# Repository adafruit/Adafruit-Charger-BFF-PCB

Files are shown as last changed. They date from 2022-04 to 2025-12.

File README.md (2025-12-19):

## Adafruit Charger BFF for QT Py PCB

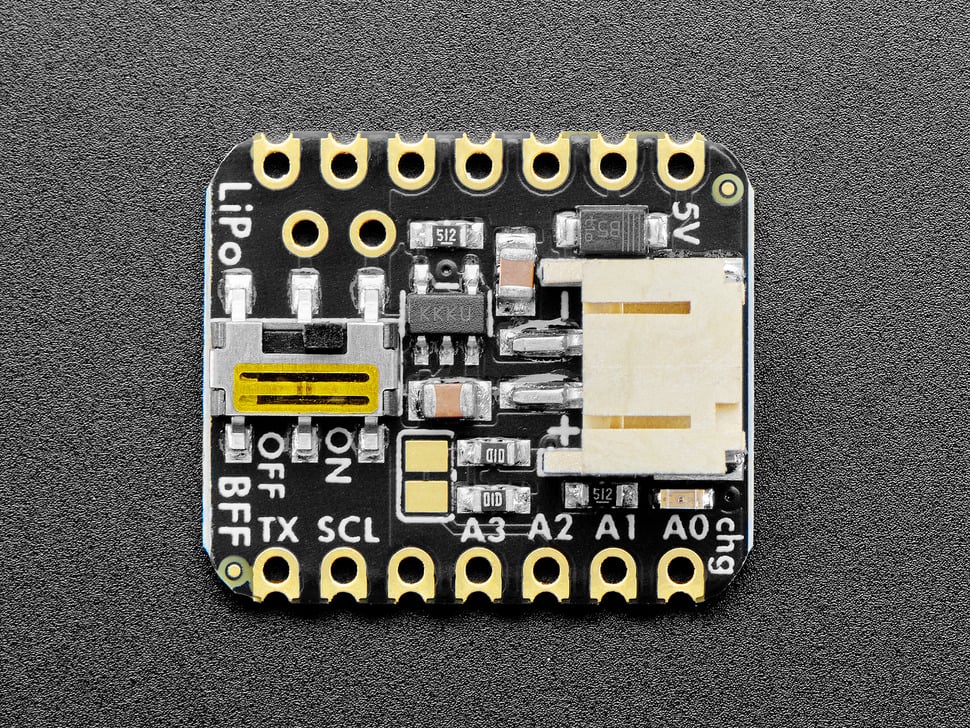
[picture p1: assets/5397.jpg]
<a href="http://www.adafruit.com/products/5397"><br/>
Click here to purchase one from the Adafruit shop</a>

PCB files for the Adafruit Charger BFF for QT Py. 

Format is EagleCAD schematic and board layout
* https://www.adafruit.com/product/5397

### Description

Is your QT Py all alone, lacking a friend to travel the wide world with? When you were a kid you may have learned about the "buddy" system, well this product is kinda like that! A board that will watch your QT Py's back and give it the power and support to wander out past your USB port.

This little lipo charger is designed to fit onto the back of any QT Py board, and make it easy for portable powering. Simply plug any standard 3.7V/4.2V lithium polymer or lithium-ion rechargeable battery into the JST plug on the end. When powered by the USB port on the QT Py, the charger kicks in and will charge up the battery at 200mA max rate. You'll see the yellow LED light up when that happens.

When the USB is removed, the battery will reverse charge into the 5V port via a Schottky diode. You can turn it on or off with the built in slide switch as well.

A simple voltage divider on the cathode side of the diode and connected to pin A2 will let your firmware detect basic modes: if the voltage is over 4.3V, it is probably plugged into USB. If the voltage is 4.2V or below its probably running on the Lipoly battery and you can roughly determine the battery state.

We include some header that you can solder to your QT Py. You can also pick up an Itsy Bitsy short female header kit to make it removable but compact, you'll just need to trim down the headers to 7 pins long.

For use with Adafruit LiPoly/LiIon batteries only! Other batteries may have different voltage, chemistry, polarity, or pinout.

* Comes as an assembled and tested PCB
* Uses the 5V input via USB Type-C connector on QT Py
* For charging single Lithium Ion/Lithium Polymer 3.7/4.2v batteries (not for older 3.6/4.1v cells)
* 200mA charge current

Batteries and QT Py are not included.

<b>Revision History:

* As of December 12, 2025 - </b> We added two breakout pads for the on/off switch for an external switch if desired. We also updated the PCB with Adafruit Pinguin to make a lovely and legible silkscreen.

### License

Adafruit invests time and resources providing this open source design, please support Adafruit and open-source hardware by purchasing products from [Adafruit](https://www.adafruit.com)!

Designed by Limor Fried/Ladyada for Adafruit Industries.

Creative Commons Attribution/Share-Alike, all text above must be included in any redistribution. 
See license.txt for additional details.

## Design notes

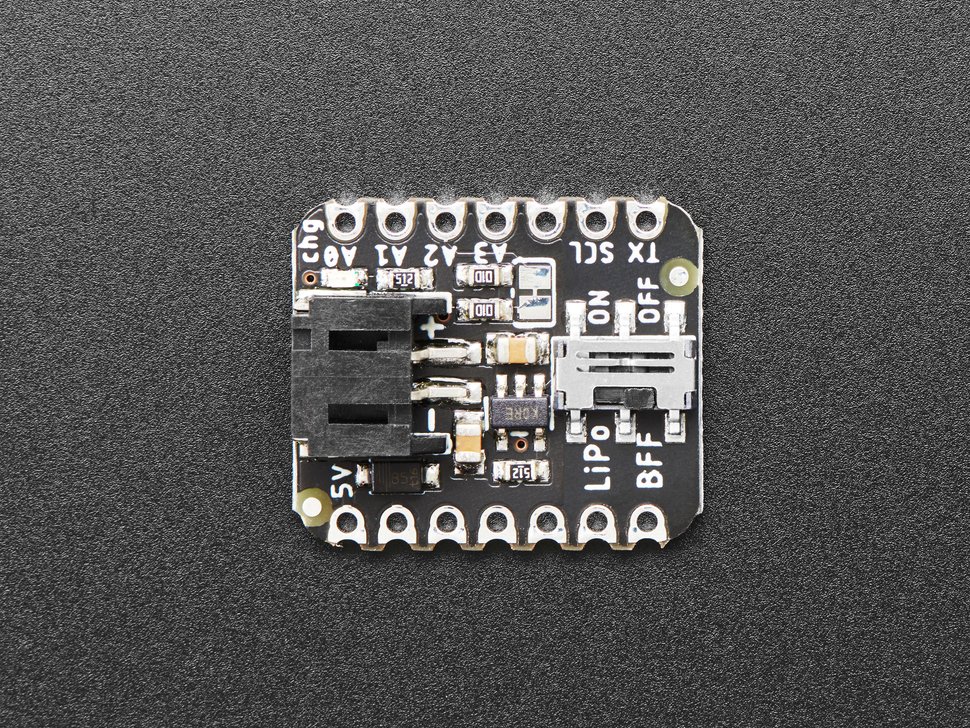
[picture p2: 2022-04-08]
assets/revA_5397.jpg

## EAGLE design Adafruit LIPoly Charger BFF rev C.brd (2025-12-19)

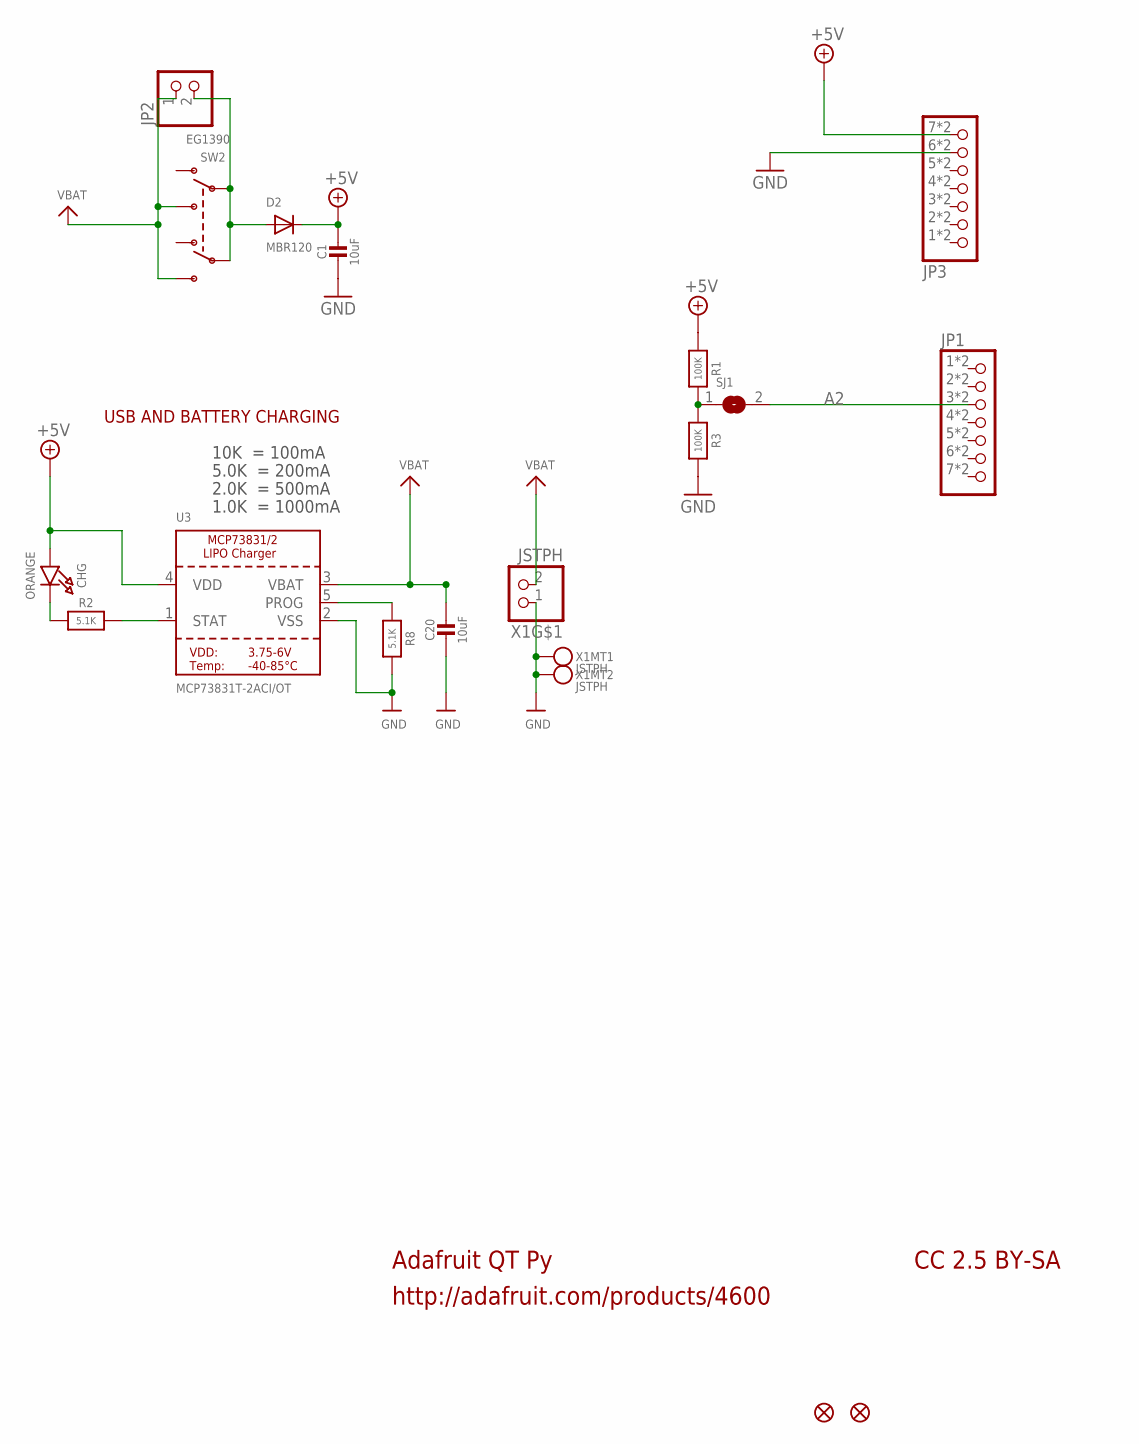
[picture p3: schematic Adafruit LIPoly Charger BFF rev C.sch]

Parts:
C1, C20: 10uF; 0805-NO
CHG: ORANGE; CHIPLED_0603_NOOUTLINE
D2: MBR120; SOD-123FL
JP1, JP3: HEADER-1X7_CASTEL; 1X07_CASTEL
JP2: HEADER-1X2ROUND; 1X02_ROUND
R1, R3: 100K; 0603-NO
R2, R8: 5.1K; 0603-NO
SJ1: SOLDERJUMPERCLOSED; SOLDERJUMPER_CLOSEDWIRE
SW2: EG1390
U3: MCP73831T-2ACI/OT; SOT23-5
U$6, U$8: FIDUCIAL_0.5MM
X1: JSTPH; JSTPH2_BATT

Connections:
+5V: C1.1, CHG.A, D2.C, JP3.7, JP3.7C (7), R1.1, U3.4 (VDD)
A2: JP1.3, JP1.3C (3), SJ1.2
GND: C1.2, C20.2, JP3.6, JP3.6C (6), R3.2, R8.2, U3.2 (VSS), X1.1, X1.NC1, X1.NC2
unnamed: R1.2, R3.1, SJ1.1
unnamed: CHG.C, R2.1
unnamed: R2.2, U3.1 (STAT)
unnamed: R8.1, U3.5 (PROG)
unnamed: D2.A, JP2.2, SW2.P1, SW2.P2
VBAT: C20.1, JP2.1, SW2.S1, SW2.S2, U3.3 (VBAT), X1.2

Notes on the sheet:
Adafruit QT Py
http://adafruit.com/products/4600
CC 2.5 BY-SA
10K = 100mA
5.0K = 200mA
2.0K = 500mA
1.0K = 1000mA
USB AND BATTERY CHARGING

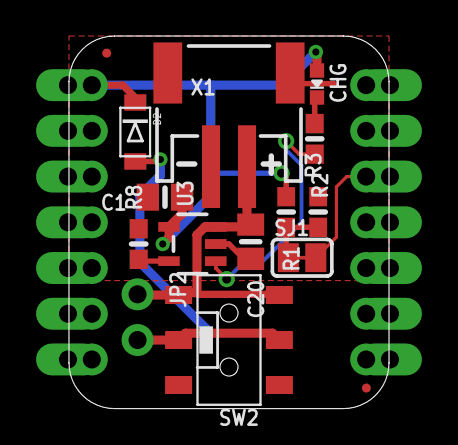
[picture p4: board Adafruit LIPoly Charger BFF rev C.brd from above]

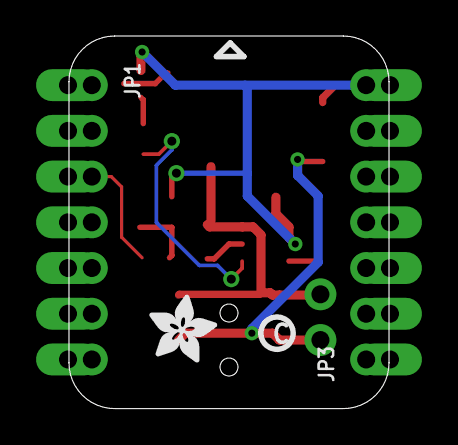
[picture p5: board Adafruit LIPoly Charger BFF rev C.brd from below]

Board: 2 copper layers, 17.8 x 20.7 mm, 34 parts (7 on the bottom side), 9 nets.

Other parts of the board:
PLABEL0: PLABEL0
PLABEL1: PLABEL1
PLABEL2: PLABEL2
PLABEL3: PLABEL3
PLABEL4: PLABEL4
PLABEL5: PLABEL5
PLABEL6: PLABEL6
PLABEL7: PLABEL7
PLABEL8: PLABEL8
PLABEL9: PLABEL9
PLABEL10: PLABEL10
PLABEL11: PLABEL11
PLABEL12: PLABEL12
PLABEL13: PLABEL13
PLABEL14: PLABEL14
U$2: ADAFRUIT_3.5MM
U$3: PCBFEAT-REV-040

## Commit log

2022-04-08 Adding board files.
    [Adafruit LIPoly Charger BFF.brd, Adafruit LIPoly Charger BFF.sch]
2025-12-19 rev c
    [Adafruit LIPoly Charger BFF rev C.brd, Adafruit LIPoly Charger BFF rev C.sch]

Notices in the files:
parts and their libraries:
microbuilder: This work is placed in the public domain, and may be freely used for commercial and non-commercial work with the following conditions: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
